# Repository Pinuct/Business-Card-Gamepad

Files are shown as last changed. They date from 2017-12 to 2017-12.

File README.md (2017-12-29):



# Business-Card-Gamepad
Hardware and software files for the Business Card Gamepad.

**IF YOU WANT MORE DETAILS ABOUT THE PROJET  ----->  [HACKADAY.IO](https://hackaday.io/project/28516-business-card-gamepad) <-----**

It contains all necesary files to make a Business Card Gamepad. With capacitive touch buttons and USB interface thought a USB micro B PCB connector. If you connect it to a PC with a USB to micro USB cable, it acts as a joystick for the host PC.

# Folders

## Arduino Code

Contains the Arduino project for the gamepad code of the business card and a touch button library (used to detect capacitive button press). The code of the .ino is simple and self explanatory, it it initializes the joystick library and the touch buttons library and loops throught the readings of the touch buttons, when there is a press it send a joystick event to the PC.

If you want to compile this code you will need to include two more libraries. This code can't not work without the great libreries that Martin Pittermann ([ADCTouch library](https://github.com/martin2250/ADCTouch)) and Matthew Heironimus ([ArduinoJoystickLibrary](https://github.com/MHeironimus/ArduinoJoystickLibrary)) did. So thanks to them to make this posible.

## Eagle PCB 

Contains an Eagle 7.50 project for the business card PCB. If you want to make it, is necesary to use a PCB of 0.6 mm thickness, needed for the USB PCB connector to be able to connect to a USB micro b cable.

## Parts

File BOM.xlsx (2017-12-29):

Parts | Qty | Value | Description | Package | Note | Reference example
JP1 | 1 |  | PIN HEADER | 2X03 | DNM
C1, C3 | 2 | 0.1uF | 0603 0.1uF Capacitor | 0603
R2 | 1 | 10K ohm | 0603 10K ohm Resistor | 0603
Y1 | 1 | 16MHz | 16 Mhz Crystal 5x3.2 mm | CRYSTAL-SMD-5X3 |  | ABM3B-16.000MHZ-10-1-U-T (http://es.farnell.com/abracon/abm3b-16-000mhz-10-1-u-t/crystal-16mhz-10pf-5-x-3-2mm/dp/2467807)
C5, C6, C10 | 3 | 1uF | 0603 1uF Capacitor | 0603
R5, R7 | 2 | 22 ohm | 0603 2 ohm Resistor | 0603
C2, C4 | 2 | 22pF | 0603 22pF Capacitor | 0603
U1 | 1 | ATMEGA32U4 | Atmel 44-pin 8-bit Microcontroller with 32KBytes of ISP Flash and USB Controller | QFN-44 |  | ATMEGA32U4-MU (http://es.farnell.com/microchip/atmega32u4-mu/mcu-8bit-atmega-16mhz-vqfn-44/dp/2425127)
B1, B2, B3, B4, B5, B6, B7, B8, B9, B10 | 10 | CAPACITIVE_BUTTON | Copper pads for capacitive buttons | - | DNM
U2 | 1 | PCB_MICRO_USB_BSS_2 | PCB USB micro b connector | - | DNM
 |  |  | DNM -> Do Not Mount

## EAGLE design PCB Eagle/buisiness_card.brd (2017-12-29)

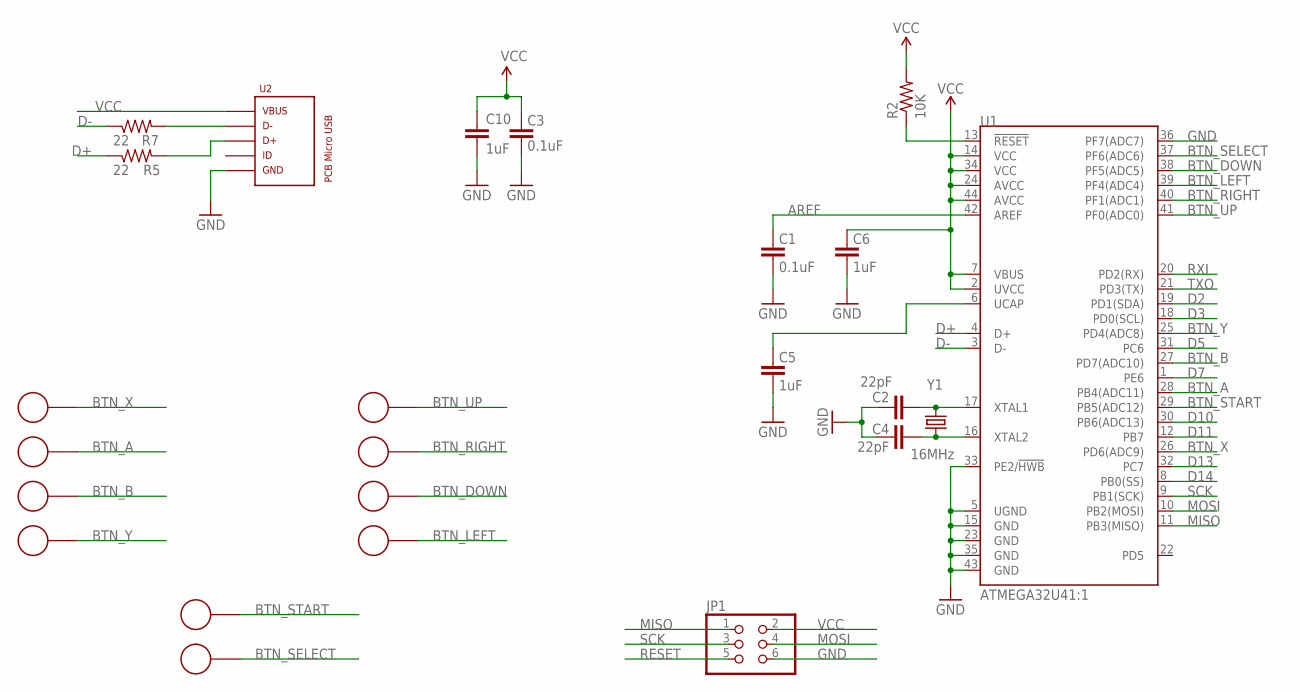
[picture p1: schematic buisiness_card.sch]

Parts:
B1, B2, B3, B4, B5, B6, B7, B8, B9, B10: CAPACITIVE_BUTTON; ROUND_CAP_BUTTON
C1, C3: 0.1uF; 0603-CAP
C2, C4: 22pF; 0603-CAP
C5, C6, C10: 1uF; 0603-CAP
JP1: PINHD-2X3; 2X03
R2: 10K; 0603-RES
R5, R7: 22; 0603-RES
U1: ATMEGA32U41:1; QFN-44-NOPAD_1:1
U2: PCB_MICRO_USB_BSS_2; USB_TYPE_B_SS_2
Y1: 16MHz; CRYSTAL-SMD-5X3

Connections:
AREF: C1.2, U1.42 (AREF)
BTN_A: B2.P$1, U1.28 (PB4(ADC11))
BTN_B: B3.P$1, U1.27 (PD7(ADC10))
BTN_DOWN: B7.P$1, U1.38 (PF5(ADC5))
BTN_LEFT: B8.P$1, U1.39 (PF4(ADC4))
BTN_RIGHT: B6.P$1, U1.40 (PF1(ADC1))
BTN_SELECT: B10.P$1, U1.37 (PF6(ADC6))
BTN_START: B9.P$1, U1.29 (PB5(ADC12))
BTN_UP: B5.P$1, U1.41 (PF0(ADC0))
BTN_X: B1.P$1, U1.26 (PD6(ADC9))
BTN_Y: B4.P$1, U1.25 (PD4(ADC8))
D2: U1.19 (PD1(SDA))
D3: U1.18 (PD0(SCL))
D5: U1.31 (PC6)
D7: U1.1 (PE6)
D10: U1.30 (PB6(ADC13))
D11: U1.12 (PB7)
D13: U1.32 (PC7)
D14: U1.8 (PB0(SS))
D+: R5.1, U1.4 (D+)
D-: R7.1, U1.3 (D-)
GND: C1.1, C2.2, C3.1, C4.2, C5.1, C6.1, C10.2, JP1.6, U1.5 (UGND), U1.15 (GND), U1.23 (GND), U1.33 (PE2/!HWB), U1.35 (GND), U1.36 (PF7(ADC7)), U1.43 (GND), U2.5
MISO: JP1.1, U1.11 (PB3(MISO))
MOSI: JP1.4, U1.10 (PB2(MOSI))
unnamed: C4.1, U1.16 (XTAL2), Y1.1
unnamed: C2.1, U1.17 (XTAL1), Y1.3 (2)
unnamed: C5.2, U1.6 (UCAP)
unnamed: R7.2, U2.2
unnamed: R5.2, U2.3
RESET: JP1.5, R2.1, U1.13 (!RESET)
RXI: U1.20 (PD2(RX))
SCK: JP1.3, U1.9 (PB1(SCK))
TXO: U1.21 (PD3(TX))
VCC: C3.2, C6.2, C10.1, JP1.2, R2.2, U1.2 (UVCC), U1.7 (VBUS), U1.14 (VCC), U1.24 (AVCC), U1.34 (VCC), U1.44 (AVCC), U2.1

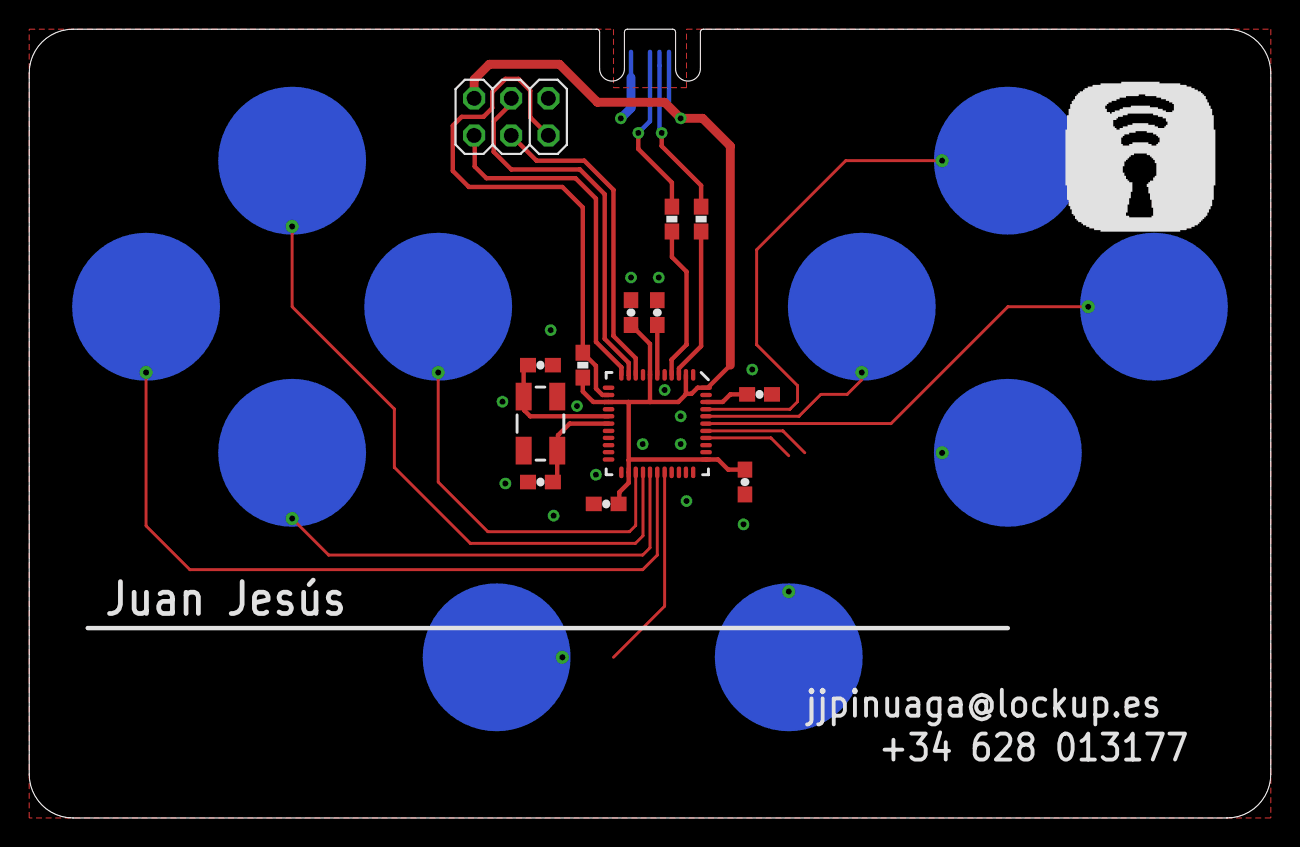
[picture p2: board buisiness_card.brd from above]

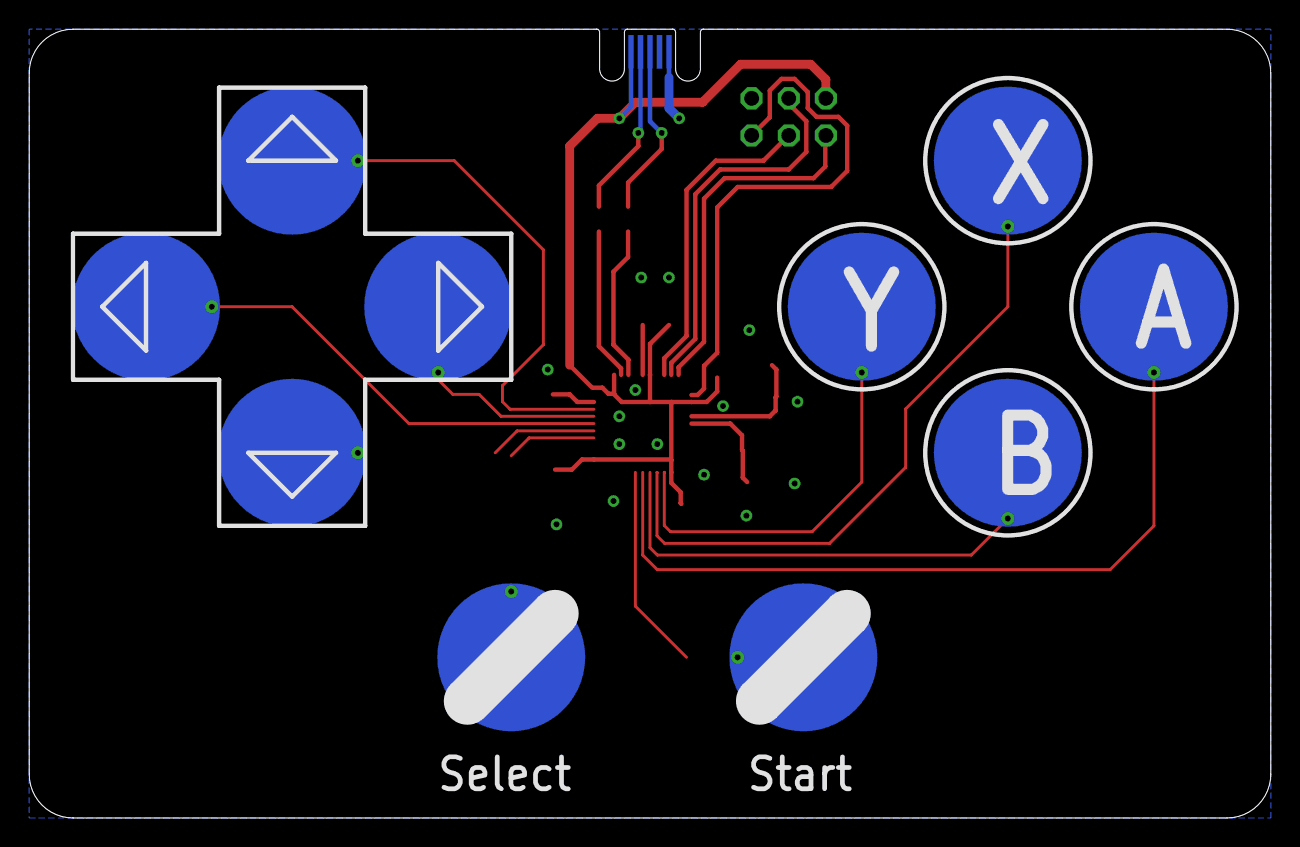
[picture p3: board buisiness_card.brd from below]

Board: 2 copper layers, 85.0 x 54.0 mm, 24 parts (11 on the bottom side), 24 nets.

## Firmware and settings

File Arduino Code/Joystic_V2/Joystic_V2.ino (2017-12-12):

#include <Joystick.h>
#include "TouchButtons.h"

Joystick_ Joystick(JOYSTICK_DEFAULT_REPORT_ID,JOYSTICK_TYPE_GAMEPAD,
  6, 0,                  // Button Count, Hat Switch Count
  true, true, false,     // X and Y, but no Z Axis
  false, false, false,   // No Rx, Ry, or Rz
  false, false,          // No rudder or throttle
  false, false, false);  // No accelerator, brake, or steering

#define NUM_BUTTONS  10
                                    // start, select, a,  b,  x,  y,  up, left, down, right
const uint8_t buttons[NUM_BUTTONS] =    {A9,    A1,   A8, A7, A11, A6, A5, A3,   A2,   A4};

void setup() 
{
  // workarround for ADC A0
  pinMode(A0, INPUT_PULLUP);

  // No pins to setup, pins can still be used regularly, although it will affect readings
  TouchButtons_initButtons(buttons, NUM_BUTTONS);
  
  // Initialize Joystick Library
  Joystick.begin();
  Joystick.setXAxisRange(-1, 1);
  Joystick.setYAxisRange(-1, 1);
} 

void loop() 
{
  
  for(int i = 0; i < NUM_BUTTONS; i++){
    
    uint8_t currentButtonState = TouchButtons_getButtonsState(i);
    
    if (currentButtonState != 0){
      
      switch (i) {
        case 0: // START
          Joystick.setButton(0, currentButtonState==1?1:0);
          break;
        case 1: // SELECT
          Joystick.setButton(1, currentButtonState==1?1:0);
          break;
        case 2: // A
          Joystick.setButton(2, currentButtonState==1?1:0);
          break;
        case 3: // B
          Joystick.setButton(3, currentButtonState==1?1:0);
          break;
        case 4: // X
          Joystick.setButton(4, currentButtonState==1?1:0);
          break;
        case 5: // Y
          Joystick.setButton(5, currentButtonState==1?1:0);
          break;
        case 6: // UP
          if (currentButtonState == 1) {
            Joystick.setYAxis(-1);
          } else {
            Joystick.setYAxis(0);
          }
          break;
        case 7: // LEFT
          if (currentButtonState == 1) {
            Joystick.setXAxis(-1);
          } else {
            Joystick.setXAxis(0);
          }
          break;
        case 8: // DOWN
          if (currentButtonState == 1) {
            Joystick.setYAxis(1);
          } else {
            Joystick.setYAxis(0);
          }
          break;
        case 9: // RIGHT
          if (currentButtonState == 1) {
            Joystick.setXAxis(1);
          } else {
            Joystick.setXAxis(0);
          }
          break;
      }
      
    }
    
  }

}

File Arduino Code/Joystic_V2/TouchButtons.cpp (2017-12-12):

/*
 * 
 *    Touch button controller
 *    Maximun 12 buttons (12 ADC inputs)
 * 
 */
 
#include "TouchButtons.h"
#include "ADCTouch.h"

// defines for setting and clearing register bits
#ifndef cbi
#define cbi(sfr, bit) (_SFR_BYTE(sfr) &= ~_BV(bit))
#endif
#ifndef sbi
#define sbi(sfr, bit) (_SFR_BYTE(sfr) |= _BV(bit))
#endif

uint16_t touchButtonsRefs[MAX_BUTTONS] = {0};
uint8_t touchButtons[MAX_BUTTONS] = {0};
uint8_t touchButtonState[MAX_BUTTONS] = {0};
uint8_t numberOfTouchButtons = 0;

void TouchButtons_initButtons(uint8_t *Buttons, uint8_t NumberOfButtons){
  
  // 12 buttons max
  if(NumberOfButtons > MAX_BUTTONS){
    return;
  }

#if FASTADC
  // set prescale to 16
  sbi(ADCSRA,ADPS2) ;
  cbi(ADCSRA,ADPS1) ;
  cbi(ADCSRA,ADPS0) ;
#endif

  numberOfTouchButtons = NumberOfButtons;
  memcpy(touchButtons, Buttons, numberOfTouchButtons);

  // get initial references
  TouchButtons_getReferences();

  
}

void TouchButtons_getReferences(){
  for(int i = 0; i < numberOfTouchButtons; i++){
    touchButtonsRefs[i] = ADCTouch.read(touchButtons[i], 500);
  }
}

// button = button number from 0 to numberOfButtons - 1 
int TouchButtons_getButtonsState(uint8_t button){

  int result = 0;
  
  // if the button is not valid
  if(button >= numberOfTouchButtons){
    return false;
  }else{
    
    // retrun touchADC value - ADCRef compared to threshold
    int value = (int)(ADCTouch.read(touchButtons[button],SAMPLES_PER_BUTTON) - touchButtonsRefs[button]);
    bool currentSatate = value > (TOUCH_THRESHOLD - touchButtonState[button] * TOUCH_HYSTERESIS);

    if(touchButtonState[button] == currentSatate){
      result = 0;
    }else{
      if(currentSatate){
        result = 1;
      }else{
        result = -1;
      }
    }
    
    touchButtonState[button] = currentSatate;

    return result;
  }
  
}

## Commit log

2017-12-12 Uploaded Eagle PCB files and Arduino code files.
    [buisiness_card.brd, buisiness_card.sch]
2017-12-29 Added BOM and updated components references.
    [BOM.xlsx, buisiness_card.brd, buisiness_card.sch]

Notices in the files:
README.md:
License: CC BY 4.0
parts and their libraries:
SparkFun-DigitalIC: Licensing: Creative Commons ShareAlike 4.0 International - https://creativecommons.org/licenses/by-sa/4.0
